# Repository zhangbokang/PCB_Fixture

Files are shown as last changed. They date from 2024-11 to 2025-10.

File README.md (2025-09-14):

# 自制PCB夹具(PCB_Fixture)
使用五金标准件和简单CNC件组成的PCB夹具。PCB fixture composed of hardware standard parts and simple CNC parts.

## 1. 简介

- 由两片CNC加工件和一些五金标准件组成，CNC加工件可以在 [嘉立创1元CNC](https://www.jlc-cnc.com/ac/ACUHiDI0/CP2tCHBI) 白嫖(没免运费券的需要出个运费两片一共十来块，也可以用二合一版回去自己锯开，可省一次运费；**PS：二合一版虽然能省一次运费，但需要自己锯开，还要稍加打磨，如果比较想完美，也没有其他要占用CNC加工次数的加工件，而且还懒得费劲，那么用单个版（不带`one`的）应该是你的第一选择，一个月两次加工次数也够了，就是差个5-6块钱的事，实际根据自己情况来就行**)。

- 相比于网上大几十甚至上百的夹具，这个夹具不仅成本低，而且可以根据需要选择光轴和丝杆长度，组成不同夹持大小的夹具。

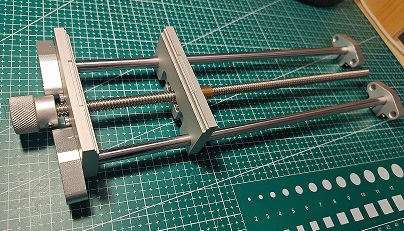
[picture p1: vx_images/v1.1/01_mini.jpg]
实物图


---
- 开源不易，来支持一下作者吧！直购链接：[【淘宝】http://e.tb.cn/h.gAQCwxIyroVmxB7?tk=MRA93pnvb30 CZ0001 「自制PCB夹具)」](http://e.tb.cn/h.gAQCwxIyroVmxB7?tk=MRA93pnvb30)
- 配件套包配合 [嘉立创1元CNC](https://www.jlc-cnc.com/ac/ACUHiDI0/CP2tCHBI) 就能完成配件收集 `(*^_^*)`

## 2. 交流群

点击链接加入群聊【子金创作交流群 855828794】：[https://qm.qq.com/q/QZsBv7JgAw](https://qm.qq.com/q/QZsBv7JgAw)

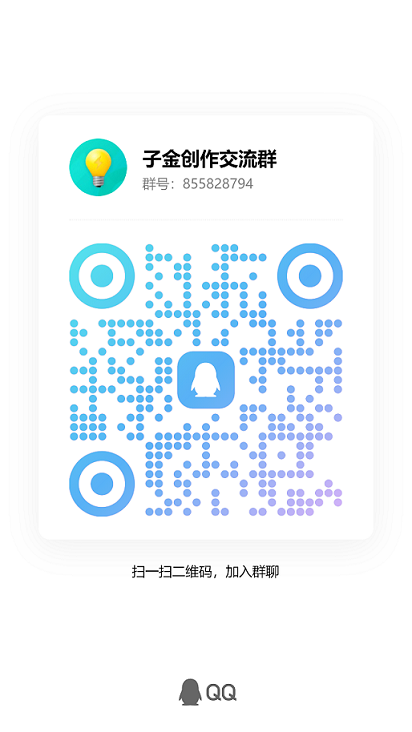
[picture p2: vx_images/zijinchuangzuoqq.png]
子金创作交流群 855828794


## 3. Release获取加工文件

- `.STEP`文件既是CNC加工文件，在加工平台加工时用的就是这个文件
- 不同加工文件具体看Release中的说明

## 4. 视频教程

- [B站-自制PCB夹具视频集合 https://space.bilibili.com/646334431/lists/4469926?type=series](https://space.bilibili.com/646334431/lists/4469926?type=series)

- [抖音-自制PCB夹具视频 https://v.douyin.com/iAJgrt8c/](https://v.douyin.com/iAJgrt8c/)

## 5. 关注我了解最新动态

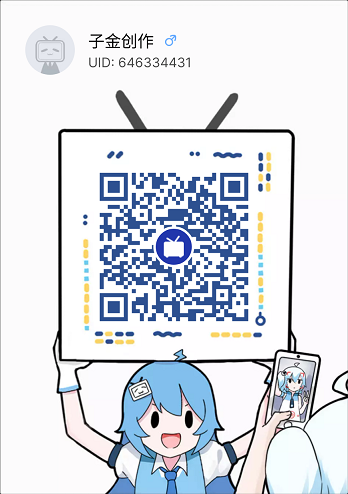
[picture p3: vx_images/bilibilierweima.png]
B站-子金创作


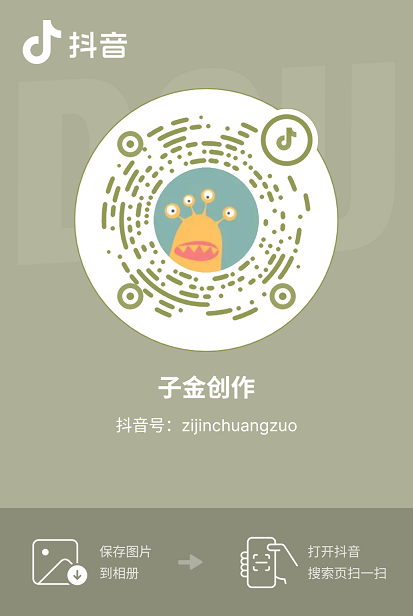
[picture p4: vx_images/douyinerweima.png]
抖音-子金创作


欢迎大家光临我的闲鱼 【闲鱼】https://m.tb.cn/h.TmkK9tq?tk=bM1le4dBSpc CZ005 「这是我的闲鱼号，快来看看吧～」

点击链接直接打开

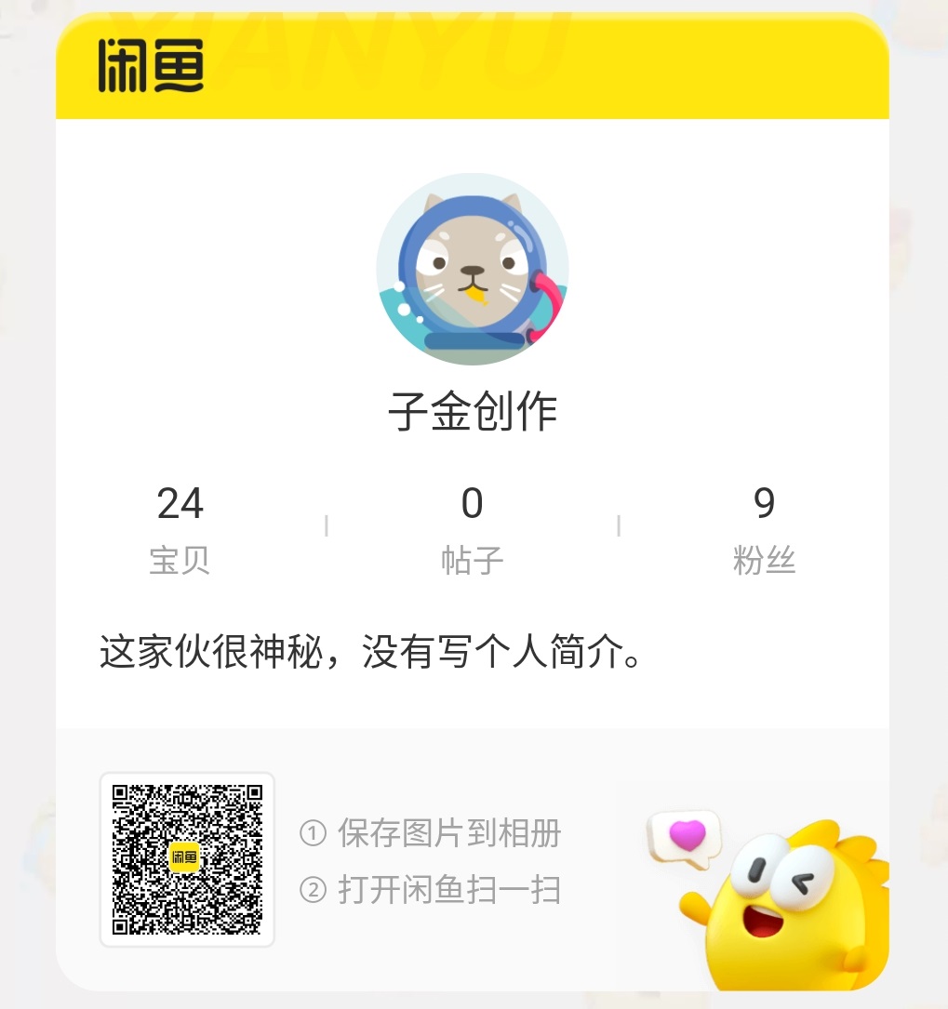
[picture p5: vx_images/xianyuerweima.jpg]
闲鱼-子金创作


## 6. 版本记录

- **v1.5**已发布(最新版本)

- 合并1.2和1.4，使用有轴套无轴套区分
- 有轴套的更换效果更好的轴套 尺寸(高8内径8外径10)
- 删除铨洲螺纹版，需要的可以查看历史版本
- 更新`BOM表.xlsx`到`bom.md`

- **v1.4.2**已发布

优化螺母孔，改槽为六角孔。
丝杆螺母朝向反了一下，并扩大了孔，可以增加一定的有效夹持尺寸。

- **v1.2.1**已发布

优化螺母孔，改槽为六角孔。
丝杆螺母朝向反了一下，并扩大了孔，可以增加一定的有效夹持尺寸。

- **v1.4.1**已发布

增加石墨轴套固定螺丝，避免某些情况下轴套滑脱的问题。

- **v1.4**已测试发布

增加石墨轴套支持

内容在`CNC加工件/嘉立创-石墨轴套改装/`文件夹

- **v1.3_A**(未发布Release，可看对应文件夹内容)(已测试但失败)

内容在`CNC加工件/嘉立创-纯光轴改装(未成功,夹不紧)/`文件夹

1. 增加纯光轴改装 (改装失败)，经测试远不如丝杆版本，故放弃改纯光轴版本。

- **v1.2**已发布

1. 增加铨洲智造的打印件(未打样测试)，铨洲智造可以支持螺纹孔，但是一个螺纹孔要加一块钱(一共要加12)，如果想成本最低，可以用嘉立创版本加工，可以兼容的；
2. 夹片靠上部位增加两个螺丝孔，可以方便后面扩展夹头(如果有的话，可以自己DIY设计，算是一个扩展吧)；

- **v1.1**已发布

1. 增加BOM表文件；
2. 优化三个杆的布局(杆更低可以倒扣着焊接插件器件)；
3. 增加二合一文件，一次就可以加工所有cnc件(需要拿回来后自己锯开，根据情况选择)；
4. 优化夹持芯片的小槽深度，夹持芯片更方便操作；

- **v1.0**已发布

1. 1.0版本为比较简单的，由两片CNC件和五金标准件组成，可以在 [嘉立创1元CNC](https://www.jlc-cnc.com/ac/ACUHiDI0/CPWXDXgd) 白嫖(没免运费券的需要出个运费两片十来块)。
2. 相比于网上大几十甚至上百的夹具，这个夹具不仅成本低，而且可以根据需要选择光轴和丝杆长度，组成不同夹持大小的夹具。

## 7. 效果图

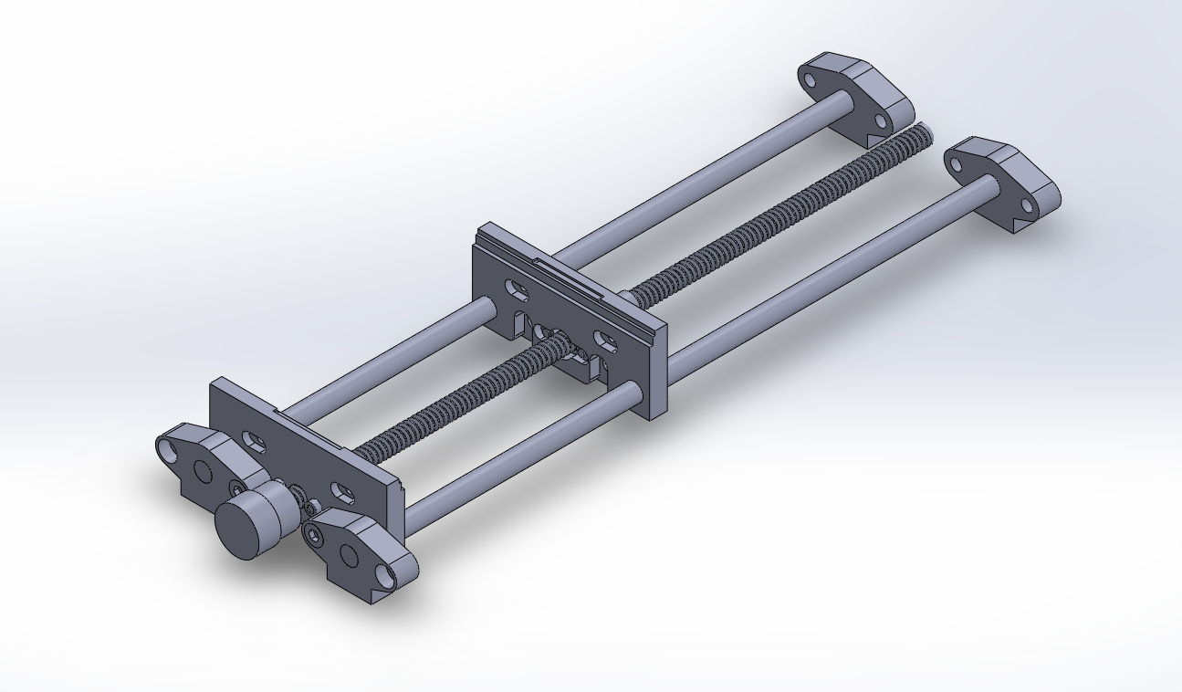
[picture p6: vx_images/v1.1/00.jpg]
装配图


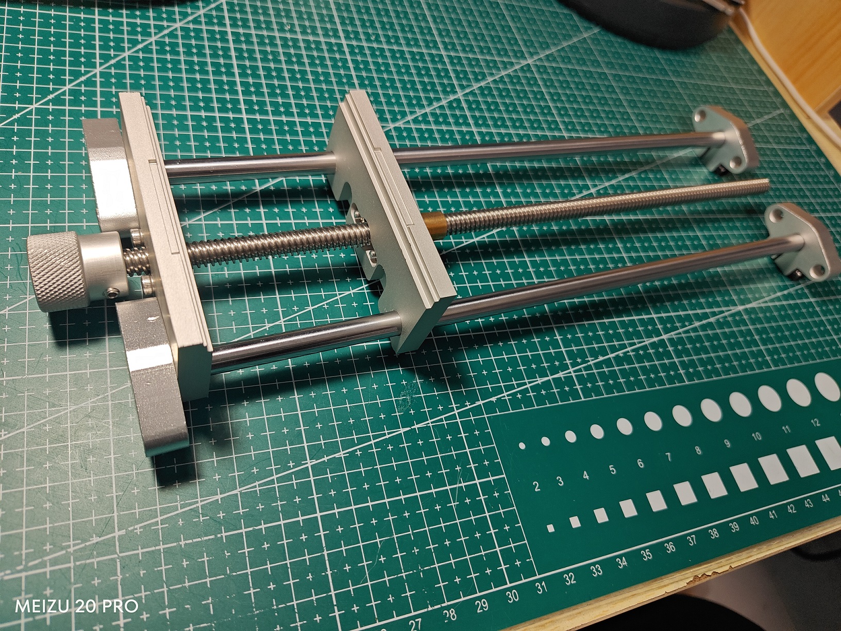
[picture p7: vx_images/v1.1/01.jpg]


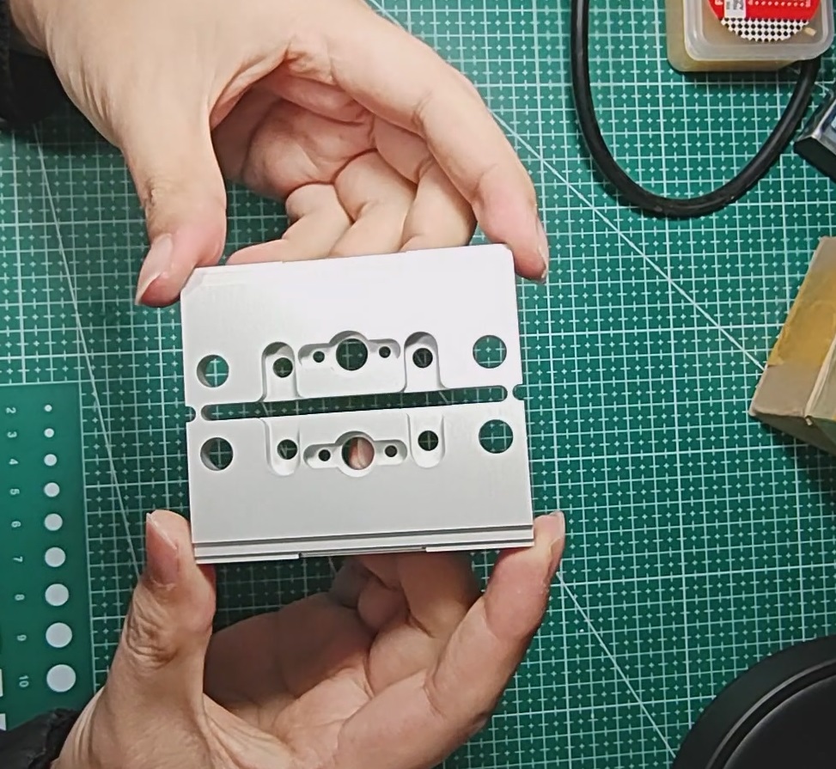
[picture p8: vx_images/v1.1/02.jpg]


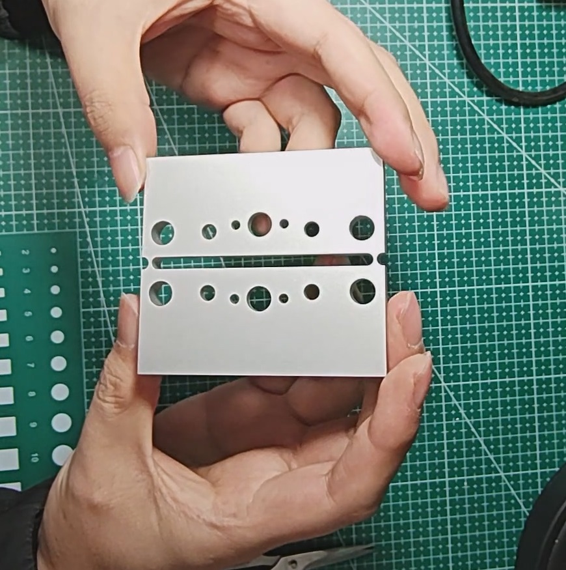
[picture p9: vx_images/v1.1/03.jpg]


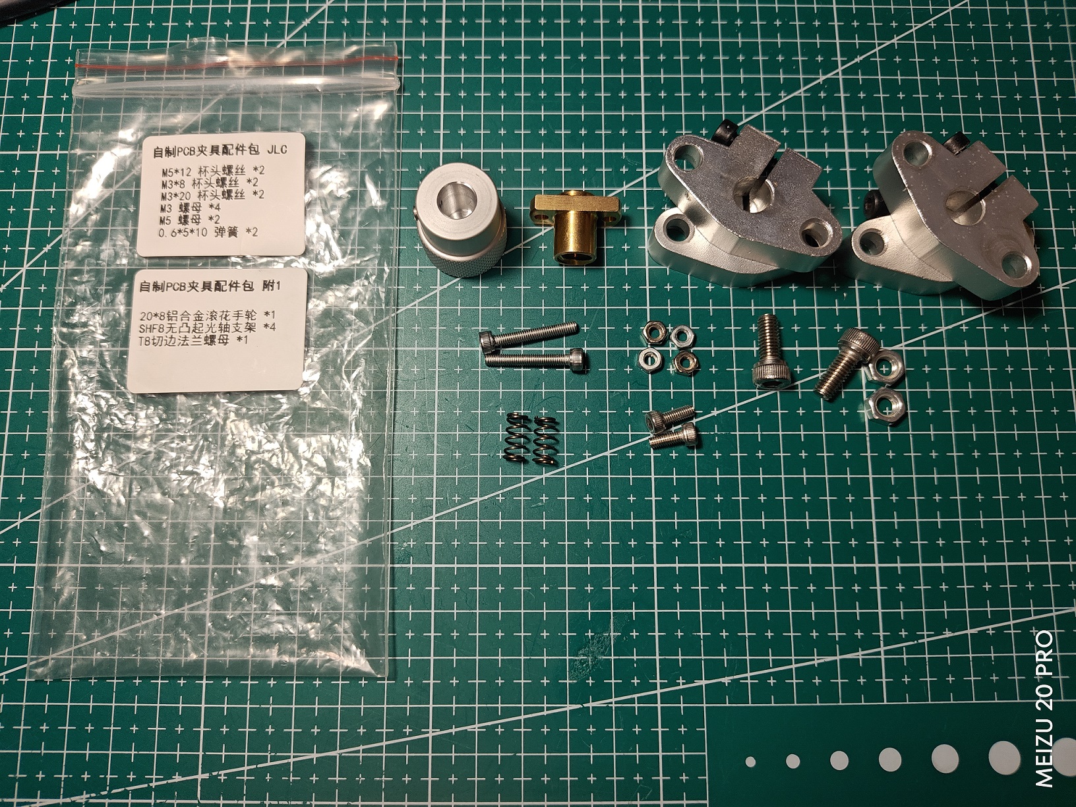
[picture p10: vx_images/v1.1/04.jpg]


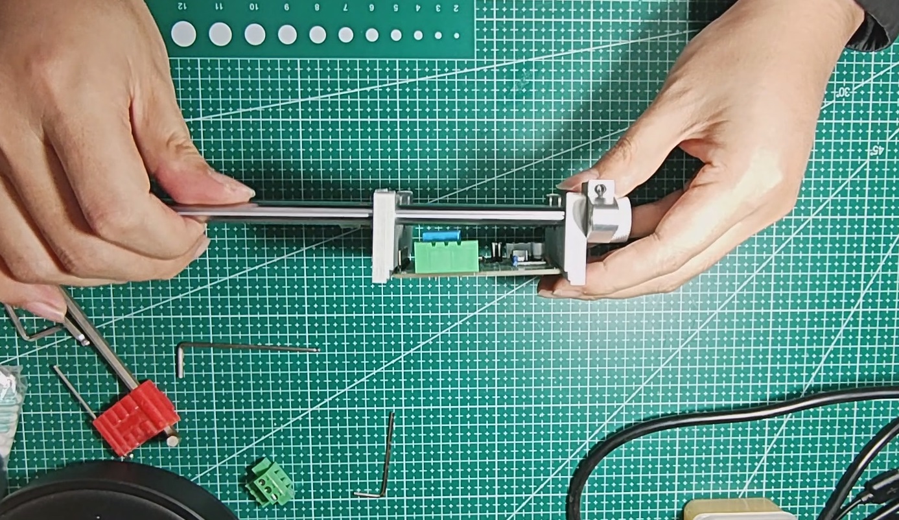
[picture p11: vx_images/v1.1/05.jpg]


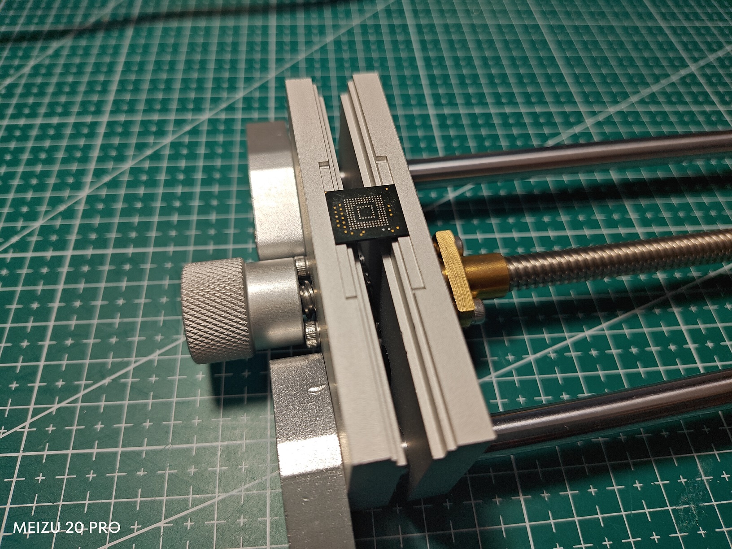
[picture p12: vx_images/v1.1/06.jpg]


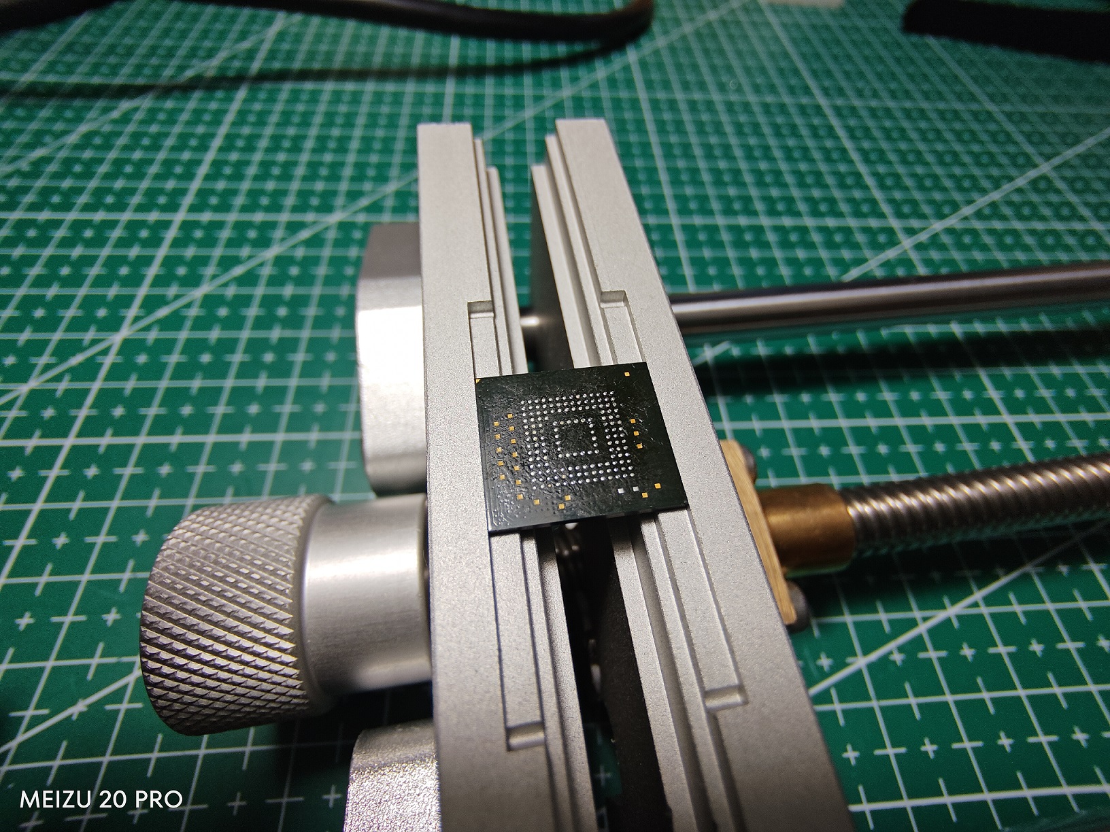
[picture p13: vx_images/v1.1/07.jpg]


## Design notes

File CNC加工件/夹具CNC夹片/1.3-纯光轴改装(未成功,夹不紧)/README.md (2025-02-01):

# v1.3_A(未成功)

制作PCB夹具请使用其他版本，该版本非PCB夹具夹片。

## 1. 说明

有反馈想要纯光轴的，所有我尝试了改装，但是失败了也可能是我改的方向不太对，白嫖的CNC有限制，暂时还没想到怎么优雅的改成可用的纯光轴版，有思路的欢迎提建议(Issues)。

## 2. Release

CNC-jlc-chunguangzhou-202411151810.STEP 改装件加工文件

## 3. 效果和预览图
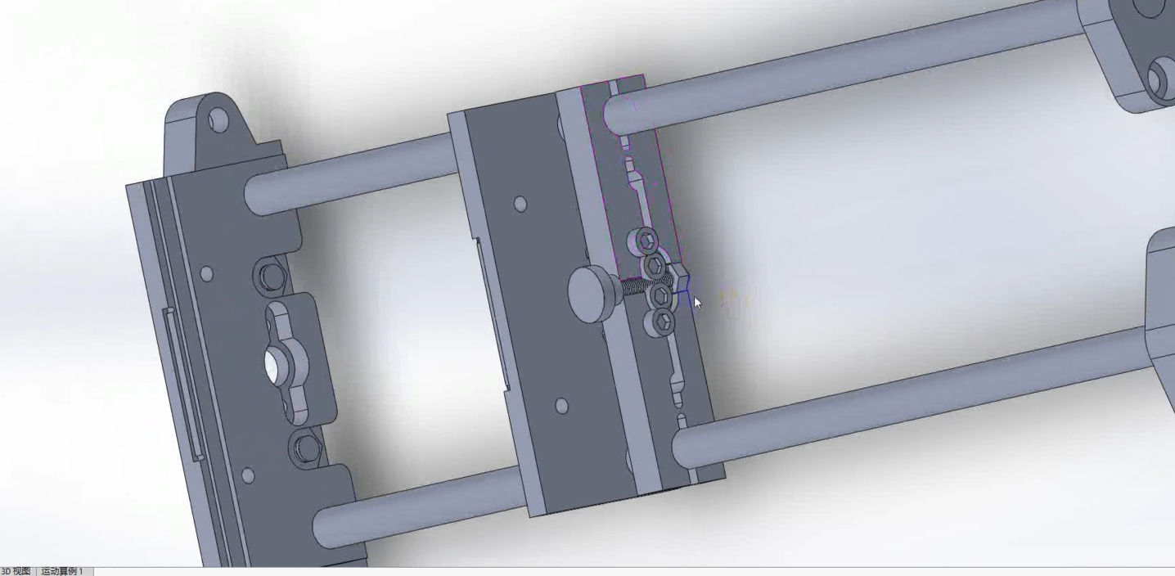
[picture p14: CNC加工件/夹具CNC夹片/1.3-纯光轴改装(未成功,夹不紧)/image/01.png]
设计效果 在这里输入图片标题

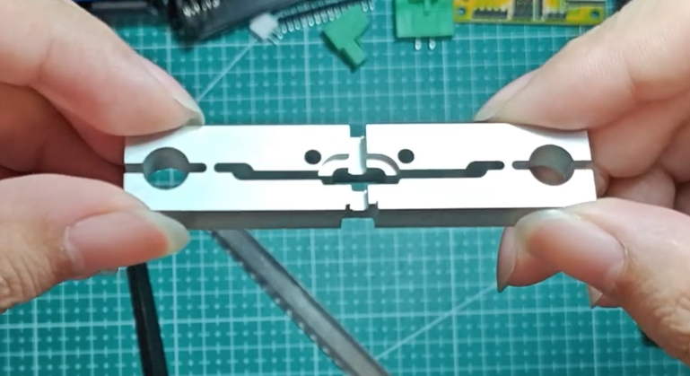
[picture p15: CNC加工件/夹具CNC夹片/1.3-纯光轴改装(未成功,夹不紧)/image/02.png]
加工件实物图1

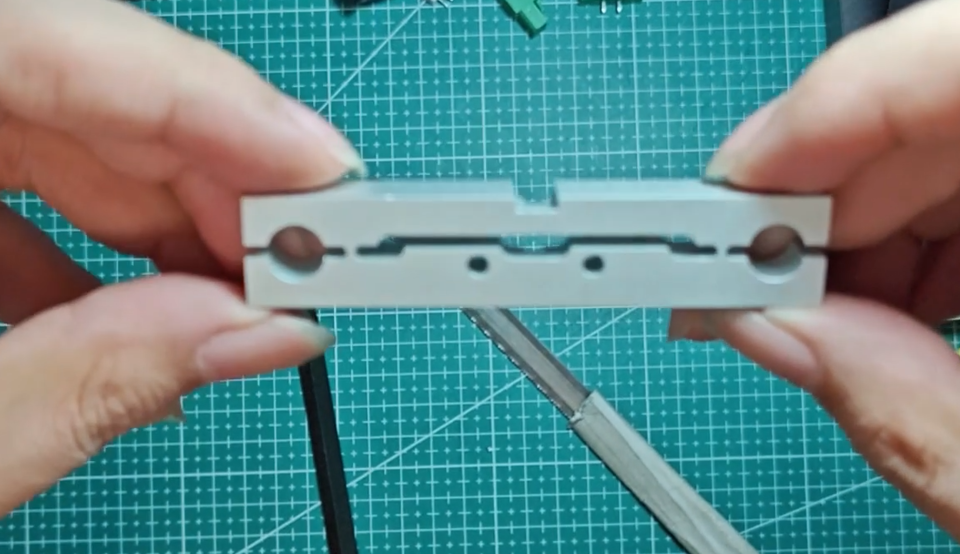
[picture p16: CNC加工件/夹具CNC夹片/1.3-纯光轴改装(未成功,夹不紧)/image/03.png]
加工件实物图2

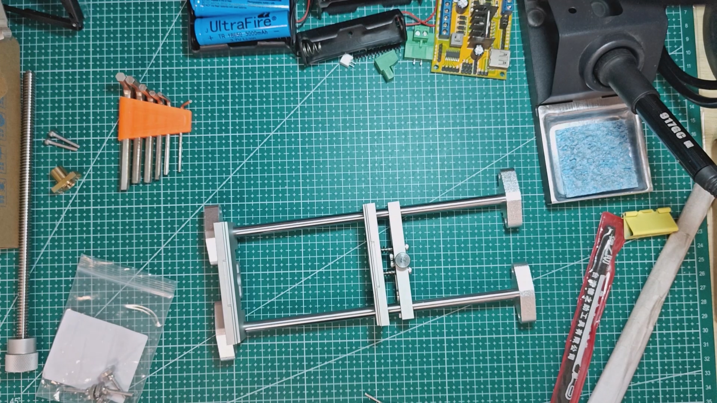
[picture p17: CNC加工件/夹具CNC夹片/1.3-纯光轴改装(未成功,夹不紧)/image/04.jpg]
组装完成效果1

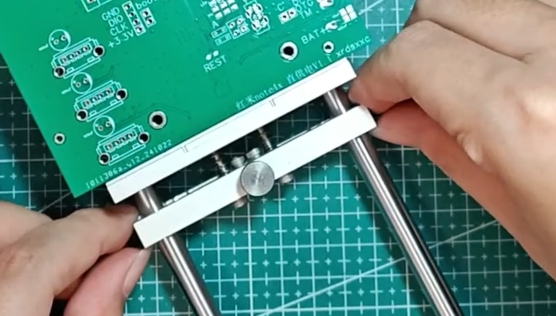
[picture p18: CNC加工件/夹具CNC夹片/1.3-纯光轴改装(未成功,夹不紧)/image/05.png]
夹持测试


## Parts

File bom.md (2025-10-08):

# 自制PCB夹具BOM表

## 1. 有轴套

【嘉立创CNC】我正在参加嘉立创CNC特价板类零件免费打样活动，点击和我一起参加免费打样CNC零件吧：
https://www.jlc-cnc.com/ac/ACUHiDI0/CP2tCHBI

> 以上即有轴套版本夹具的所有物品清单，也可以直接从我这购买配件包，或者订购整套成品！
>
> 感觉不错就来支持一下作者吧！
>
> 直购链接：[【淘宝】http://e.tb.cn/h.gAQCwxIyroVmxB7?tk=MRA93pnvb30 CZ0001 「自制PCB夹具)」](http://e.tb.cn/h.gAQCwxIyroVmxB7?tk=MRA93pnvb30)

| 编号 | 名称 | 图片 | 数量 | 类型 | 备注 |
| ---- | --- | --- | --- | --- | --- |
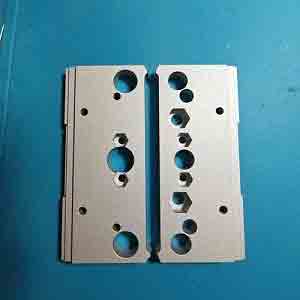
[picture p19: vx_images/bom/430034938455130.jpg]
夹具CNC加工件
| 1 | [夹具CNC加工件](http://e.tb.cn/h.gAQCwxIyroVmxB7?tk=MRA93pnvb30) |  | one版本\*1(或固定\*1+活动\*1) | CNC加工件  | [【嘉立创CNC】特价板类零件免费打样活动 https://www.jlc-cnc.com/ac/ACUHiDI0/CP2tCHBI](https://www.jlc-cnc.com/ac/ACUHiDI0/CP2tCHBI) 如果使用合一的加工，可以省一次的钱，但需要收到后自己锯开，自己没法加工的或者嫌麻烦，或者求完美的，可以加工非合一的，一个月两次也够，就是会多一次邮费 |
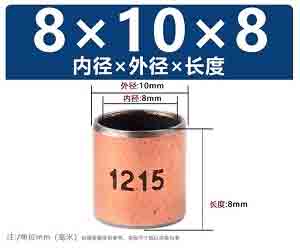
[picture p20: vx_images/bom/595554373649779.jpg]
复合轴套
| 2 | 复合轴套 高8内径8外径10 |  | 2 | 五金标准件 | |
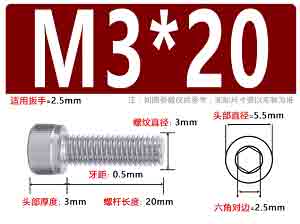
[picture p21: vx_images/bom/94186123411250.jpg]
M3×20螺丝
| 3 | M3×20螺丝(18~20都可以) |  | 2 | 五金标准件 | |
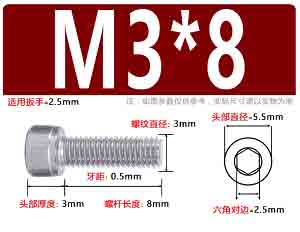
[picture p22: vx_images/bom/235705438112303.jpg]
M3×18螺丝
| 4 | M3×8螺丝(6~8都可以) |  | 2 | 五金标准件 | |
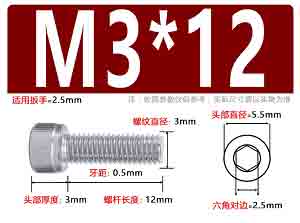
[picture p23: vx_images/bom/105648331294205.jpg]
M3×12螺丝
| 5 | M3×12螺丝 |  | 2 | 五金标准件 | |
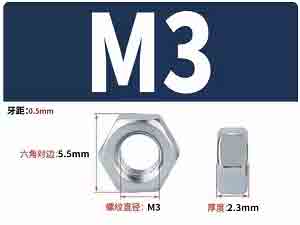
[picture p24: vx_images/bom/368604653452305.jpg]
M3六角螺母
| 6 | M3六角螺母 |  | 4 | 五金标准件 | |
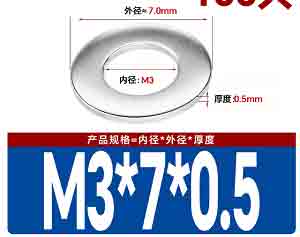
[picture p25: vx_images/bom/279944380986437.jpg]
M3垫片
| 7 | M3垫片 |  | 4 | 五金标准件 | |
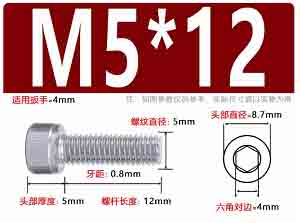
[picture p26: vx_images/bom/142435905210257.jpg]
M5×12螺丝
| 8 | M5×12杯头螺丝(10~12都可以) |  | 2 | 五金标准件 | |
| 9 | M5六角螺母 | M5六角螺母 | 2 | 五金标准件 | |
| 10 | 0.6×5×10弹簧 | 0.6×5×10弹簧 | 2 | 五金标准件 | |
| 11 | 沉孔SHF8-卧式支架光轴支架 | 沉孔SHF8-卧式支架光轴支架 | 4 | 五金标准件 | |
| 12 | 光轴8mm | 光轴8mm | 夹持PCB尺寸+5cm\*2 | 五金标准件 | |
| 13 | T8丝杆 | T8丝杆 | 夹持PCB尺寸+5cm\*1 | 五金标准件 | 推荐导程8,短的可以用2mm导程(默认)或4mm导程，长的建议用8mm导程，下单丝杆时可以备注;下单时记得备注要切边法兰螺母 |
| 14 | T8切边螺母 | T8切边螺母 | 1 | 五金标准件 | 一般和丝杆配套使用，也就是导程螺距一样，建议和丝杆同时购买，单独购买时一定要说清楚导程螺距不然可能不能用 |
| 15 | 铝合金手轮圆形旋钮(外径20内径8) | 铝合金手轮圆形旋钮 | 1 | 五金标准件 | |

组装视频教程

- [B站-自制PCB夹具视频集合 https://space.bilibili.com/646334431/lists/4469926?type=series](https://space.bilibili.com/646334431/lists/4469926?type=series)

- [抖音-自制PCB夹具视频 https://v.douyin.com/iAJgrt8c/](https://v.douyin.com/iAJgrt8c/)

## 2. 无轴套

【嘉立创CNC】我正在参加嘉立创CNC特价板类零件免费打样活动，点击和我一起参加免费打样CNC零件吧：
https://www.jlc-cnc.com/ac/ACUHiDI0/CP2tCHBI

> 以下即有轴套版本夹具的所有物品清单，也可以直接从我这购买配件包，或者订购整套成品！
>
> 感觉不错就来支持一下作者吧！
>
> 直购链接：[【淘宝】http://e.tb.cn/h.gAQCwxIyroVmxB7?tk=MRA93pnvb30 CZ0001 「自制PCB夹具)」](http://e.tb.cn/h.gAQCwxIyroVmxB7?tk=MRA93pnvb30)

| 编号 | 名称 | 图片 | 数量 | 类型 | 备注 |
| ---- | --- | --- | --- | --- | --- |
| 1 | [夹具CNC加工件](http://e.tb.cn/h.gAQCwxIyroVmxB7?tk=MRA93pnvb30) | 夹具CNC加工件 | one版本\*1(或固定\*1+活动\*1) | CNC加工件  | [【嘉立创CNC】特价板类零件免费打样活动 https://www.jlc-cnc.com/ac/ACUHiDI0/CP2tCHBI](https://www.jlc-cnc.com/ac/ACUHiDI0/CP2tCHBI) 如果使用合一的加工，可以省一次的钱，但需要收到后自己锯开，自己没法加工的或者嫌麻烦，或者求完美的，可以加工非合一的，一个月两次也够，就是会多一次邮费 |
| 2 | M3×20螺丝(18~20都可以) | M3×20螺丝 | 2 | 五金标准件 | |
| 3 | M3×8螺丝(6~8都可以) | M3×18螺丝 | 2 | 五金标准件 | |
| 4 | M3六角螺母 | M3六角螺母 | 4 | 五金标准件 | |
| 5 | M5×12杯头螺丝(10~12都可以) | M5×12螺丝 | 2 | 五金标准件 | |
| 6 | M5六角螺母 | M5六角螺母 | 2 | 五金标准件 | |
| 7 | 0.6×5×10弹簧 | 0.6×5×10弹簧 | 2 | 五金标准件 | |
| 8 | 沉孔SHF8-卧式支架光轴支架 | 沉孔SHF8-卧式支架光轴支架 | 4 | 五金标准件 | |
| 9 | 光轴8mm | 光轴8mm | 夹持PCB尺寸+5cm\*2 | 五金标准件 | |
| 10 | T8丝杆 | T8丝杆 | 夹持PCB尺寸+5cm\*1 | 五金标准件 | 推荐导程8,短的可以用2mm导程(默认)或4mm导程，长的建议用8mm导程，下单丝杆时可以备注;下单时记得备注要切边法兰螺母 |
| 11 | T8切边螺母 | T8切边螺母 | 1 | 五金标准件 | 一般和丝杆配套使用，也就是导程螺距一样，建议和丝杆同时购买，单独购买时一定要说清楚导程螺距不然可能不能用 |
| 12 | 铝合金手轮圆形旋钮(外径20内径8) | 铝合金手轮圆形旋钮 | 1 | 五金标准件 | |

组装视频教程

- [B站-自制PCB夹具视频集合 https://space.bilibili.com/646334431/lists/4469926?type=series](https://space.bilibili.com/646334431/lists/4469926?type=series)

- [抖音-自制PCB夹具视频 https://v.douyin.com/iAJgrt8c/](https://v.douyin.com/iAJgrt8c/)

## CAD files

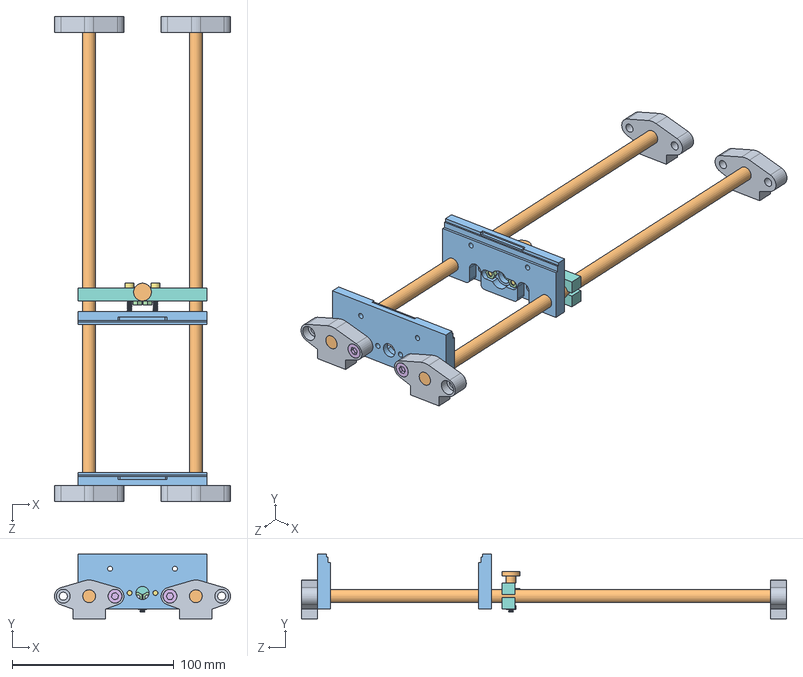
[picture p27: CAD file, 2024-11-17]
CNC加工件/夹具CNC夹片/1.3-纯光轴改装(未成功,夹不紧)/PCB夹具装配图-嘉立创-纯光轴改装.SLDASM
109.0 x 40.0 x 300.0 mm
SHF8-卧式支架光轴支架 x 4
光轴8mm x 2
CNC加工件-嘉立创 x 2
M3六角螺母 x 5
M5六角螺母 x 2
M5×12杯头螺丝 x 2
M3×20杯头螺丝 x 2
CNC加工件-嘉立创-纯光轴改装
M3×8杯头螺丝 x 2
M3×20手拧螺丝

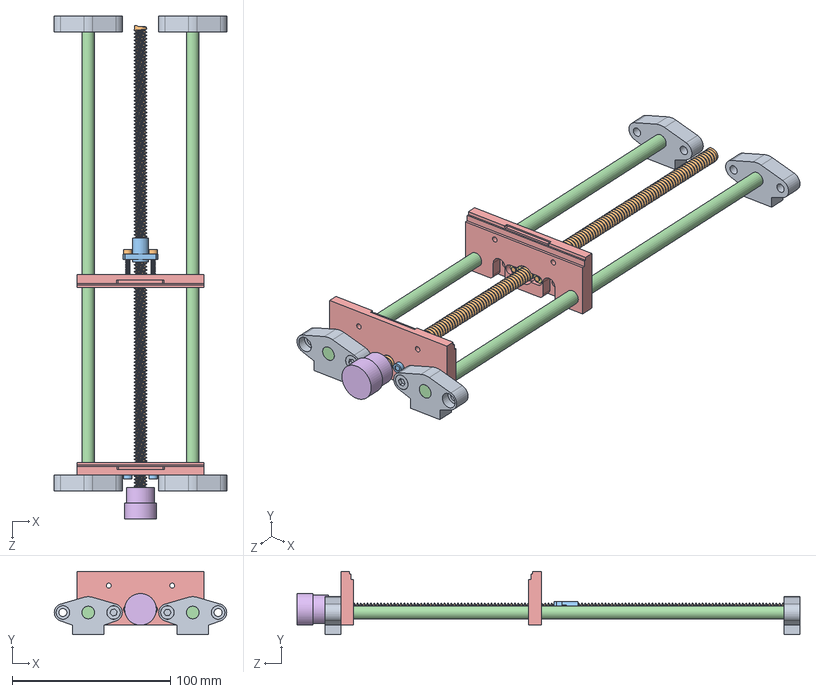
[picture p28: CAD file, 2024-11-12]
PCB夹具装配图-嘉立创.SLDASM
109.0 x 40.0 x 317.7 mm
SHF8-卧式支架光轴支架 x 4
T8螺杆
T8切边法兰
光轴8mm x 2
CNC加工件-嘉立创 x 2
铝合金手轮圆形旋钮
M3六角螺母 x 4
M5六角螺母 x 2
M5×12杯头螺丝 x 2
M3×20杯头螺丝 x 2
M3×6平头或沉头螺丝 x 2

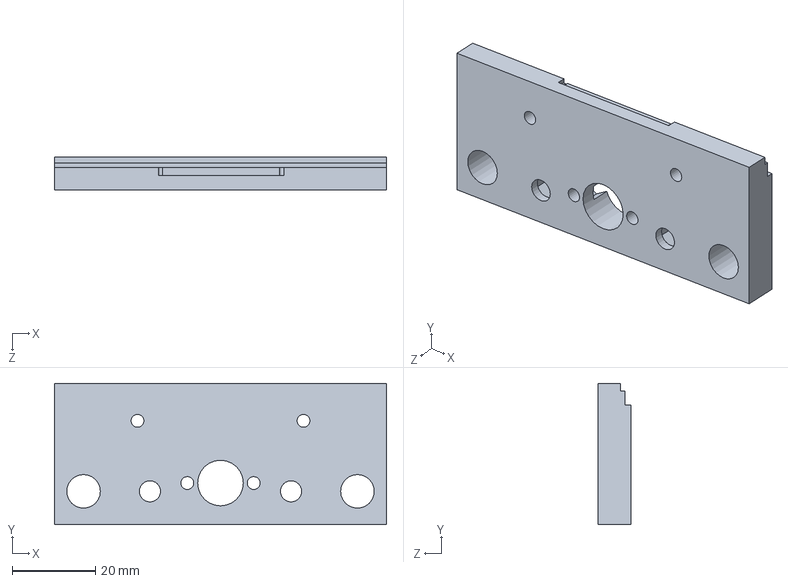
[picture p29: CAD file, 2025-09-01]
CNC加工件/夹具CNC夹片/1.2/CNC加工件-嘉立创-活动.SLDPRT
80.0 x 34.0 x 8.00 mm

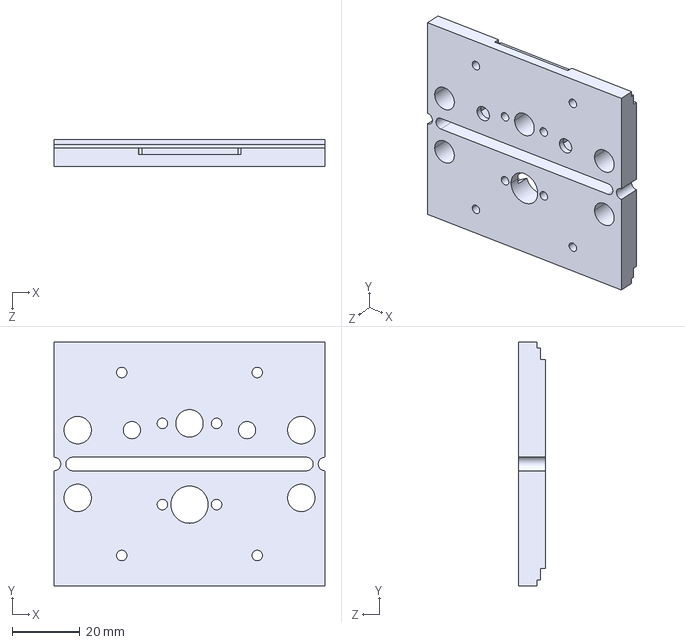
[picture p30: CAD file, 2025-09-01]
CNC加工件/夹具CNC夹片/1.2/step加工文件/CNC加工件-嘉立创-v1.2.1_one-20250901.STEP
80.0 x 72.0 x 8.00 mm

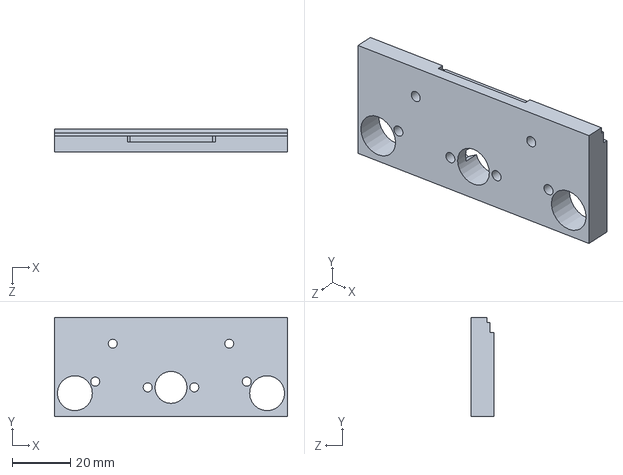
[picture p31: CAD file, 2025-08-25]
CNC加工件/夹具CNC夹片/1.4/CNC加工件-嘉立创-活动.SLDPRT
80.0 x 34.0 x 8.00 mm

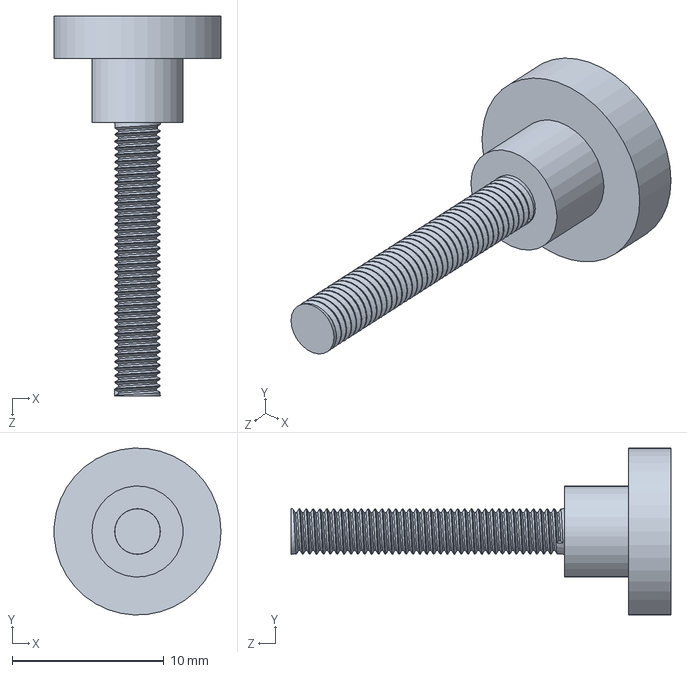
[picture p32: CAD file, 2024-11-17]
五金标准件/M3×20手拧螺丝.SLDPRT
11.0 x 11.0 x 25.0 mm

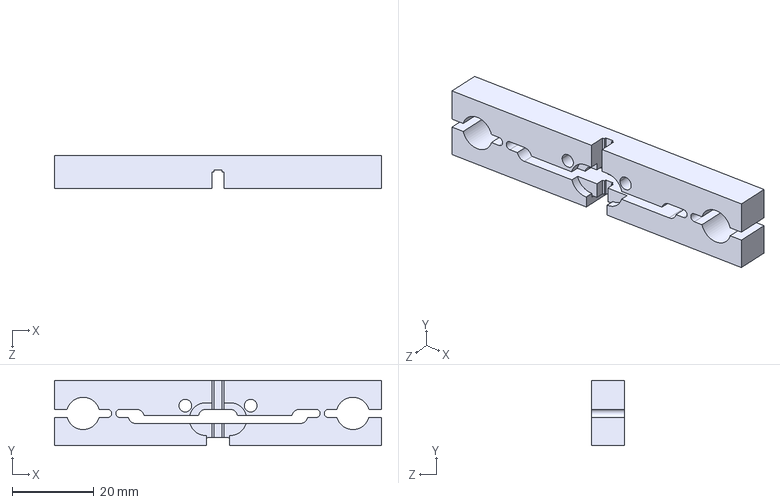
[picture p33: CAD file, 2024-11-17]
CNC加工件/夹具CNC夹片/1.3-纯光轴改装(未成功,夹不紧)/CNC加工件-嘉立创-纯光轴改装-202411151810.STEP
80.0 x 16.0 x 8.00 mm

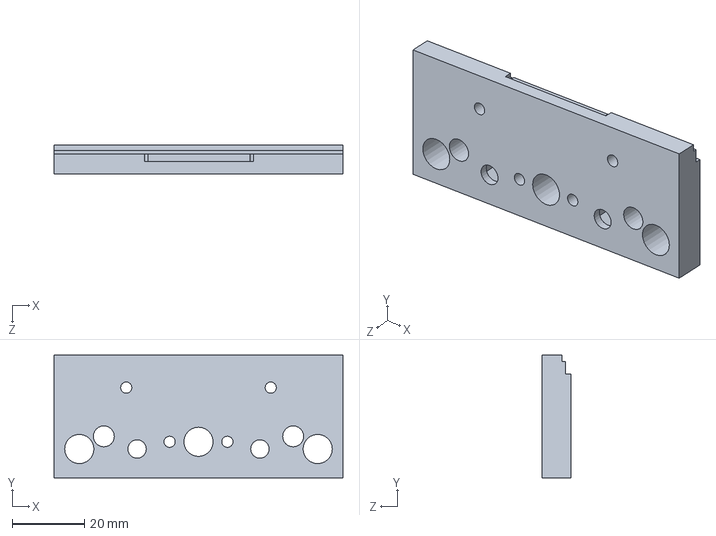
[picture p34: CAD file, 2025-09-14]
CNC加工件/夹具CNC夹片/1.5/CNC加工件-有轴套-固定.SLDPRT
80.0 x 34.0 x 8.00 mm

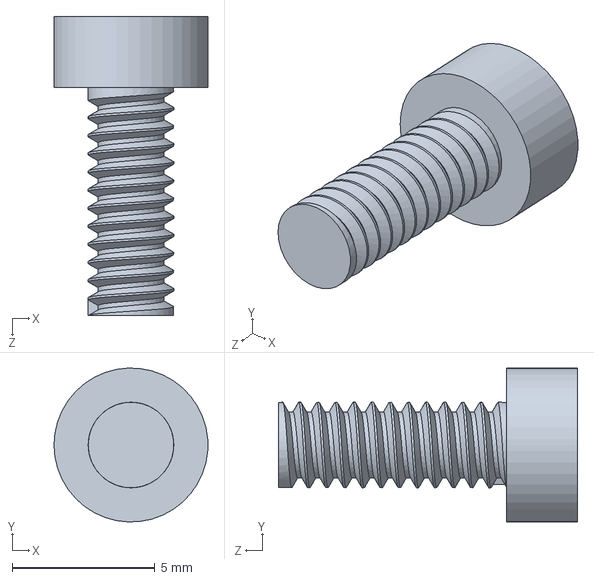
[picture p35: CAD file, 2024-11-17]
五金标准件/M3×8杯头螺丝.SLDPRT
5.40 x 5.40 x 10.5 mm

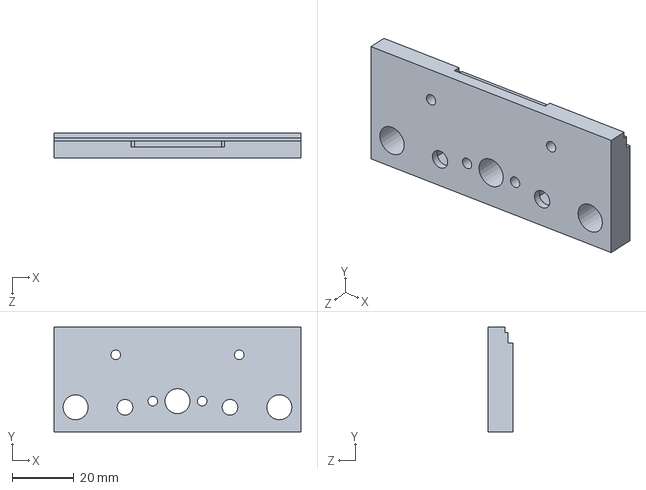
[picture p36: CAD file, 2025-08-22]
CNC加工件/夹具CNC夹片/1.2/CNC加工件-嘉立创-固定.SLDPRT
80.0 x 34.0 x 8.00 mm

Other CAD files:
CNC加工件/夹具CNC夹片/1.4/step加工文件/CNC加工件-v1.4.2_嘉立创_one-20250825.STEP
CNC加工件/夹具CNC夹片/1.5/CNC加工件-有轴套_one.SLDPRT
CNC加工件/夹具CNC夹片/1.5/step加工文件/CNC加工件-1.5-yzt-hd-20250914.STEP
CNC加工件/夹具CNC夹片/1.2/CNC加工件-嘉立创_one.SLDPRT
CNC加工件/夹具CNC夹片/1.2/step加工文件/CNC加工件-嘉立创-v1.2.1_活动-20250901.STEP
CNC加工件/夹具CNC夹片/1.4/CNC加工件-嘉立创_one.SLDPRT
CNC加工件/夹具CNC夹片/1.4/step加工文件/CNC加工件-v1.4.2_嘉立创-活动-20250825.STEP
CNC加工件/夹具CNC夹片/1.5/step加工文件/CNC加工件-1.5-yzt-gd-20250914.STEP
CNC加工件/夹具CNC夹片/1.2/step加工文件/CNC加工件-嘉立创-v1.2-202411072042.STEP
CNC加工件/夹具CNC夹片/1.2/step加工文件/CNC加工件-嘉立创-v1.2.1_固定-20250823.STEP
CNC加工件/夹具CNC夹片/1.2/step加工文件/CNC加工件-嘉立创-v1.2_one-202411072042.STEP
CNC加工件/夹具CNC夹片/1.3-纯光轴改装(未成功,夹不紧)/CNC加工件-嘉立创-纯光轴改装.SLDPRT
CNC加工件/夹具CNC夹片/1.4/CNC加工件-嘉立创-固定.SLDPRT
CNC加工件/夹具CNC夹片/1.4/step加工文件/CNC加工件-v1.4.0_嘉立创-固定-20250407.STEP
CNC加工件/夹具CNC夹片/1.4/step加工文件/CNC加工件-v1.4.0_嘉立创-活动-20250407.STEP
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

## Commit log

2024-11-01 v1.1 1.降低螺杆和光轴，优化夹持有插件的PCB 2.优化中间夹持芯片的卡口 3.手轮处增加螺丝优化对加工件的磨损 4.修改切边法兰处的弹簧和螺丝 5.增加BOM表文件
    [BOM表.xlsx, CNC加工件.SLDPRT, M3×20杯头螺丝.SLDPRT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]
2024-11-04 v1.1 整理BOM表
    [BOM表.xlsx]
2024-11-04 v1.1 完善说明文件
2024-11-04 v1.1 1.完善零件 2.增加爆炸图 3.增加一次CNC(注意合一的一次CNC需要收到后切断，如果嫌麻烦可以下单两个同样的非合一的即可)
    [CNC加工件.SLDPRT, CNC加工件_one.SLDPRT, M3×6平头或沉头螺丝.SLDPRT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]
2024-11-04 v1.1 完善BOM表
    [BOM表.xlsx]
2024-11-04 v1.1 说明文件增加视频教程
2024-11-04 v1.1 完善git排除文件
2024-11-04 v1.1 完善二合一CNC文件
    [CNC加工件_one.SLDPRT]
2024-11-05 v1.1_A 二合一CNC增加2mm版，避免连接处被识别为小于1mm导致不能白嫖，优先使用one，不行再试试one_2mm
    [CNC加工件_one_2mm.SLDPRT]
2024-11-07 v1.1 更新说明文件
2024-11-12 v1.2 1.增加铨洲智造的CNC打样 2.优化嘉立创版本CNC细节
    [BOM表.xlsx, CNC加工件-嘉立创-v1.2-202411072042.STEP, CNC加工件-嘉立创-v1.2_one-202411072042.STEP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]
2024-11-12 v1.2 3.嘉立创版去掉one_2mm版(因为增加了两个孔，所以one版被迫增改为连接处为1.5mm的宽带，所以不存在1mm问题)
    [CNC加工件-嘉立创_one_2mm.SLDPRT, CNC加工件-铨洲-v1.2_one_2mm-202411072042.STEP]
2024-11-12 v1.2 更新说明文件
2024-11-13 v1.2 修改文件名
    [CNC加工件-铨洲-v1.2-202411072042.STEP, CNC加工件-铨洲-v1.2_one-202411072042.STEP, CNC加工件-铨洲.SLDPRT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]
2024-11-17 v1.3 增加纯光轴改装
    [CNC加工件-嘉立创-纯光轴改装-202411151810.STEP, CNC加工件-嘉立创-纯光轴改装.SLDPRT, M3×20手拧螺丝.SLDPRT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]
2024-11-17 v1.3 更新说明文件
2024-12-02 v1.3 未改装成功，夹不紧
    [CNC加工件-嘉立创-纯光轴改装-202411151810.STEP, CNC加工件-嘉立创-纯光轴改装.SLDPRT, PCB夹具装配图-嘉立创-纯光轴改装.SLDASM]
2024-12-02 v1.3_A 修改说明文件
2025-01-25 修改说明文件
2025-02-01 修改说明文件，去除无用的发布，放到对应文件夹下，并增加说明文件
2025-07-19 更新v1.4版本，增加活动块使用石墨轴套
    [CNC加工件-v1.4.0_嘉立创-固定-20250407.STEP, CNC加工件-v1.4.0_嘉立创-活动-20250407.STEP, CNC加工件-v1.4.0_嘉立创_one-20250407.STEP]
2025-07-29 优化石墨轴套版本，解决轴套可能滑脱的问题
    [CNC加工件-v1.4.0_嘉立创-固定-20250407.STEP, CNC加工件-v1.4.0_嘉立创-活动-20250407.STEP, CNC加工件-v1.4.0_嘉立创_one-20250407.STEP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]
2025-08-22 优化螺母孔
    [CNC加工件-v1.4.2_嘉立创-固定-20250823.STEP, CNC加工件-v1.4.2_嘉立创-活动-20250823.STEP, CNC加工件-v1.4.2_嘉立创_one-20250823.STEP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]
2025-08-23 优化说明文件版本相关说明
2025-08-25 优化1.4.2版本
    [CNC加工件-v1.4.2_嘉立创-活动-20250825.STEP, CNC加工件-v1.4.2_嘉立创_one-20250825.STEP, CNC加工件-嘉立创-活动.SLDPRT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]
2025-09-01 优化v1.2.1
    [CNC加工件-v1.4.2_嘉立创-活动-20250823.STEP, CNC加工件-v1.4.2_嘉立创_one-20250823.STEP, CNC加工件-嘉立创-v1.2.1_one-20250823.STEP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]
2025-09-06 - 合并1.2和1.4，使用有轴套无轴套区分 - 更换效果更好的轴套 - 删除铨洲螺纹版，需要的可以查看历史版本(不推荐使用，后面可能会专门适配)
    [CNC加工件-1.5-无轴套_one-20250907.STEP, CNC加工件-1.5-无轴套_固定-20250907.STEP, CNC加工件-1.5-无轴套_活动-20250907.STEP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]
2025-09-14 - **v1.5.0**
    - 合并1.2和1.4，使用有轴套无轴套区分
    - 有轴套的更换效果更好的轴套 尺寸(高8内径8外径10)
    - 删除铨洲螺纹版，需要的可以查看历史版本
    - 更新BOM表.xlsx到[bom.md 点击查看](bom.md)
    [BOM表.xlsx, CNC加工件-有轴套-固定.SLDPRT, CNC加工件-有轴套-活动.SLDPRT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]
2025-09-14 - **v1.5.0**
    - 更新BOM表.xlsx到bom.md
    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
    [2020铝型材-100mm.SLDPRT, 2020铝型材-120-顶部无孔.SLDPRT, 2020铝型材-120.SLDPRT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]
2025-09-14 更新说明文件
2025-10-08 更新bom文件
2025-11-26 删除多的文件
    [2020铝型材-100mm.SLDPRT, 2020铝型材-120-顶部无孔.SLDPRT, 2020铝型材-120.SLDPRT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]
